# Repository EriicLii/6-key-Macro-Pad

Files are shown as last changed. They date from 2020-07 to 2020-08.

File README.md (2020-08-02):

# 6 Key Macro Pad

Footprints from https://github.com/tmk/keyboard_parts.pretty and https://github.com/egladman/keebs.pretty

Components used from https://github.com/tmk/kicad_lib_tmk

Built with SMD components, and ATMega32u4.

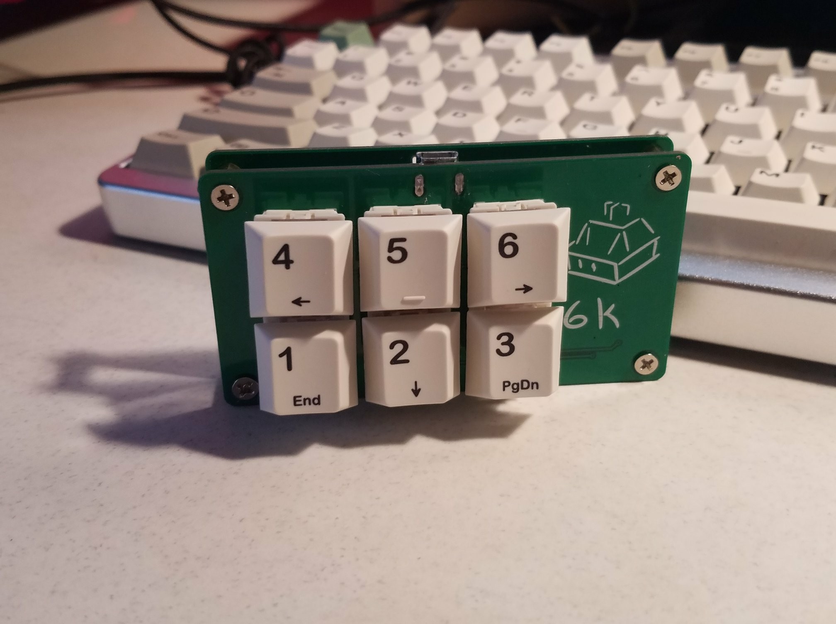
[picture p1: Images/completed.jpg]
build image


PCB:
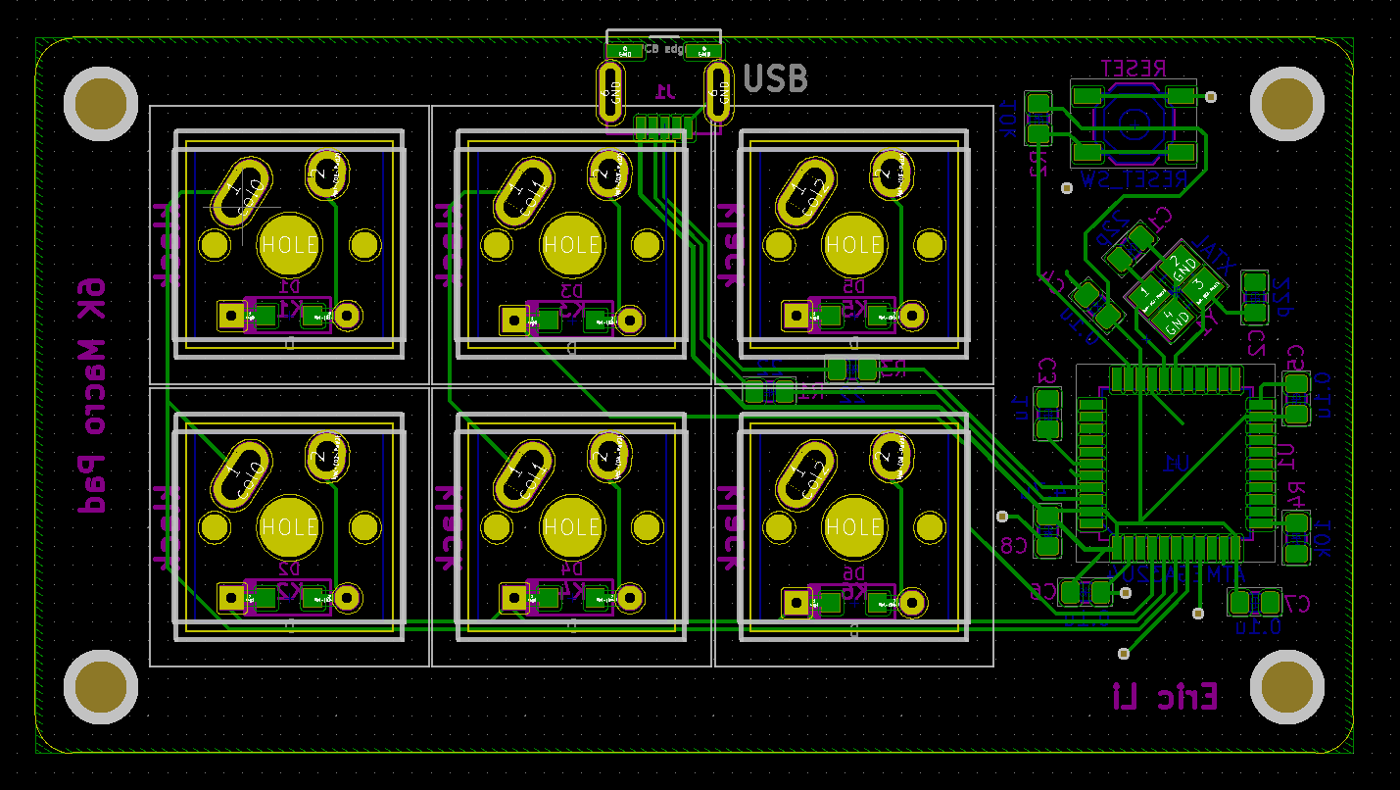
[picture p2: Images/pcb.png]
PCB Image


Schematic:
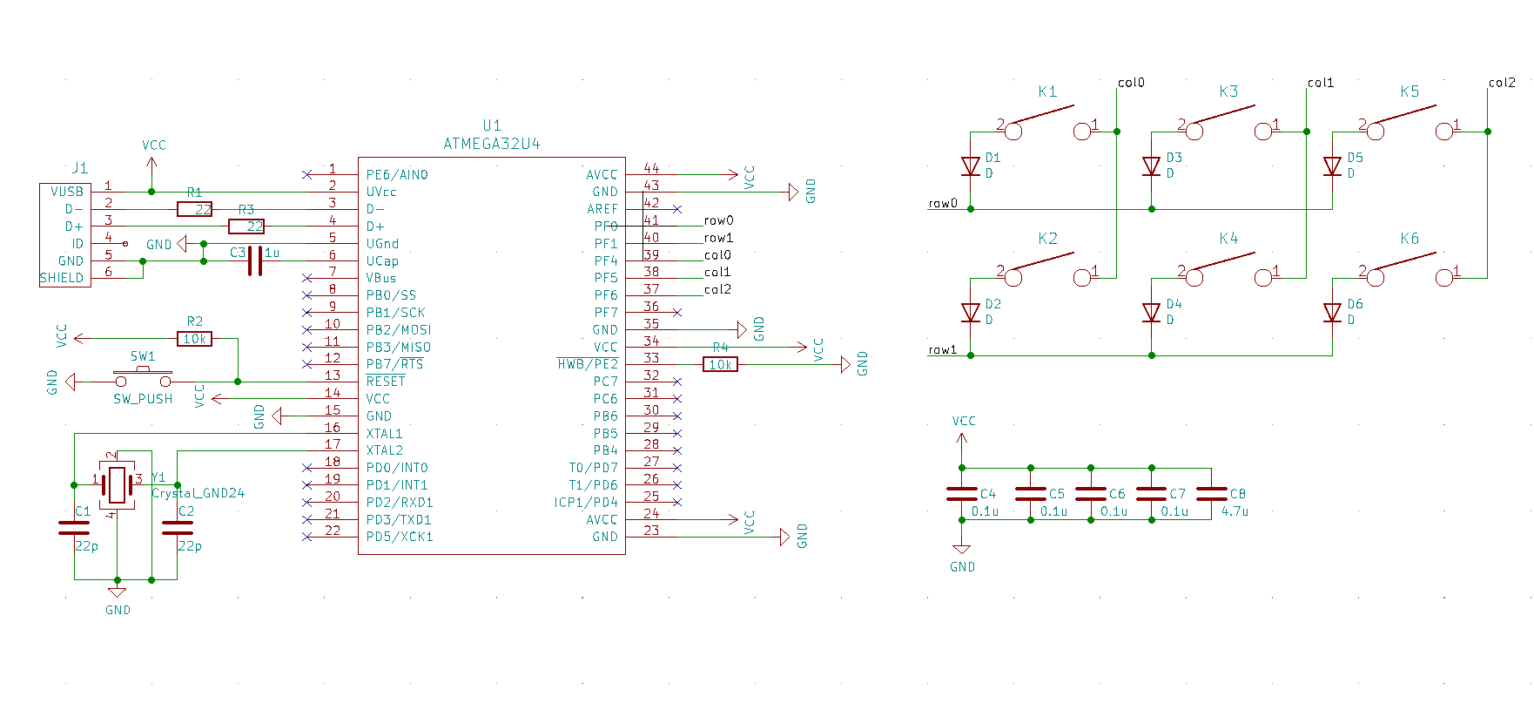
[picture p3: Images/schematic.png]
Schematic


## Update 7/31
Finally got to soldering the parts. 
Had an issue with discovering the DFU. At first I though the microcontroller didn't come with the HWBE bit set from factory. However after painstakingly soldering the MOSI, MISO and SCK pins, then setting the fuses through ISP -- still no dice. I finally noticed that I hadn't wired VBus to VCC in my schematic. I guess I got taught the lesson of measuring thrice before sending it to fabrication.

QMK firmware setup was very easy. Kudos to everyone involved in the project as the abundance documentation and organization made it simple to get a new keyboard firmware set up. Right now I only have the option to manually change the keymaps in QMK then recompile. I'll perhaps attempt to make a Via keymap later as well. (Also I need to add pictures of the build!)

## Update 8/2
Added some pictures. You can see how I had to wire VCC to the Vbus pin on the back of the board.

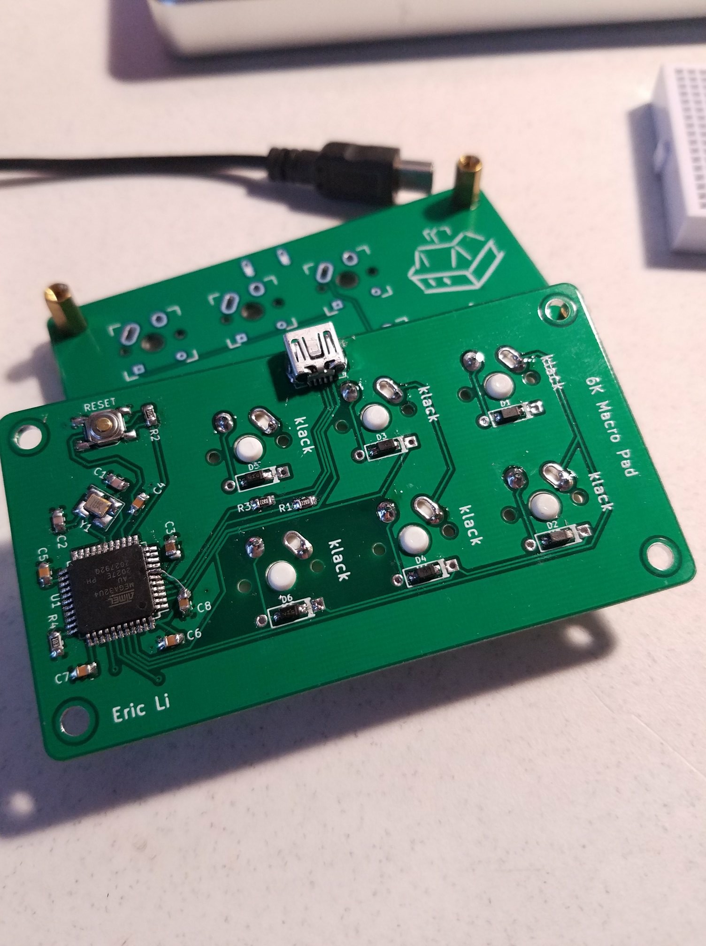
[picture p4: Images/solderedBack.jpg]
back image


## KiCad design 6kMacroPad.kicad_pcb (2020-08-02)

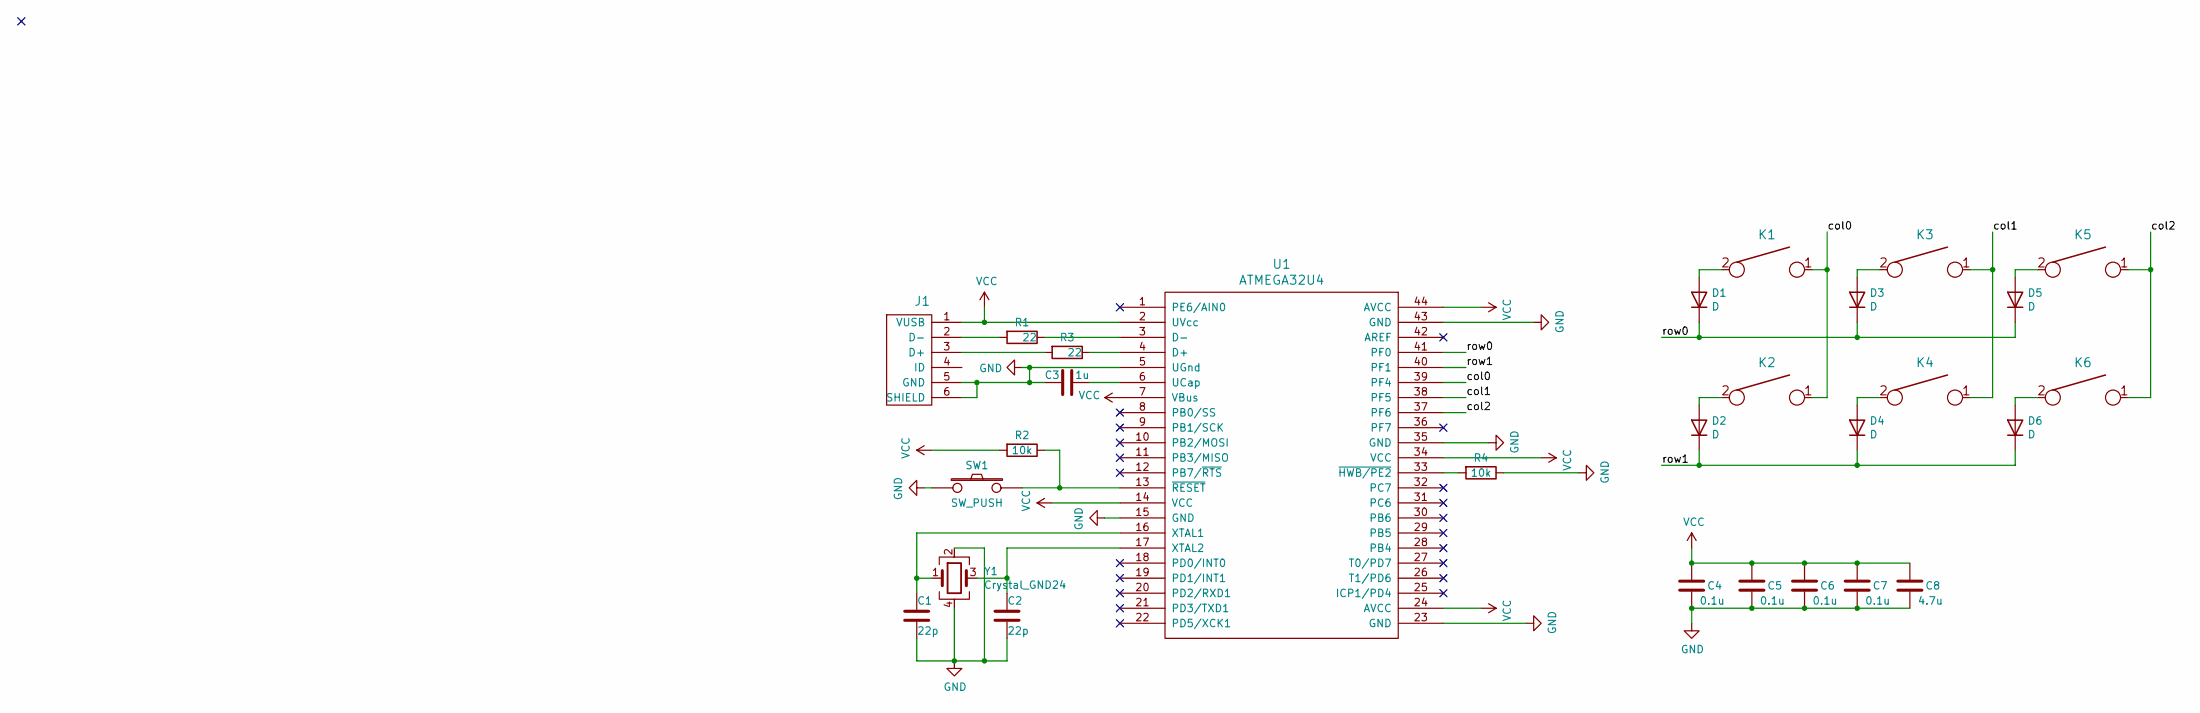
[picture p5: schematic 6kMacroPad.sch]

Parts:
C1, C2: 22p; C_0805_2012Metric_Pad1.15x1.40mm_HandSolder
C3: 1u; C_0805_2012Metric_Pad1.15x1.40mm_HandSolder
C4, C5, C6, C7: 0.1u; C_0805_2012Metric_Pad1.15x1.40mm_HandSolder
C8: 4.7u; C_0805_2012Metric_Pad1.15x1.40mm_HandSolder
D1, D2, D3, D4, D5, D6: D; D_SOD123_axial
J1: USB_mini_micro_B; USB_miniB_hirose_5S8
K1, K2, K3, K4, K5, K6: KEYSW; Mx_Alps_100
R1, R3: 22; R_0805_2012Metric_Pad1.15x1.40mm_HandSolder
R2, R4: 10k; R_0805_2012Metric_Pad1.15x1.40mm_HandSolder
SW1: SW_PUSH; SW_SPST_TL3342
U1: ATMEGA32U4; TQFP-44_10x10mm_P0.8mm
Y1: Crystal_GND24; Crystal_SMD_SeikoEpson_FA238-4Pin_3.2x2.5mm_HandSoldering

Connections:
/col0: K1.1, K2.1, U1.39 (PF4)
/col1: K3.1, K4.1, U1.38 (PF5)
/col2: K5.1, K6.1, U1.37 (PF6)
/row0: D1.1 (K), D3.1 (K), D5.1 (K), U1.41 (PF0)
/row1: D2.1 (K), D4.1 (K), D6.1 (K), U1.40 (PF1)
GND: C1.2, C2.2, C3.2, C4.2, C5.2, C6.2, C7.2, C8.2, J1.5 (GND), J1.6 (SHIELD), R4.1, SW1.1, U1.5 (UGnd), U1.15 (GND), U1.23 (GND), U1.35 (GND), U1.43 (GND), Y1.2, Y1.4
unnamed: C1.1, U1.16 (XTAL1), Y1.1
unnamed: C2.1, U1.17 (XTAL2), Y1.3
unnamed: C3.1, U1.6 (UCap)
unnamed: D1.2 (A), K1.2
unnamed: D2.2 (A), K2.2
unnamed: D3.2 (A), K3.2
unnamed: D4.2 (A), K4.2
unnamed: D5.2 (A), K5.2
unnamed: D6.2 (A), K6.2
unnamed: J1.2 (D-), R1.2
unnamed: J1.3 (D+), R3.2
unnamed: R1.1, U1.3 (D-)
unnamed: R2.1, SW1.2, U1.13 (~RESET)
unnamed: R3.1, U1.4 (D+)
unnamed: R4.2, U1.33 (~HWB/PE2)
VCC: C4.1, C5.1, C6.1, C7.1, C8.1, J1.1 (VUSB), R2.2, U1.2 (UVcc), U1.7 (VBus), U1.14 (VCC), U1.24 (AVCC), U1.34 (VCC), U1.44 (AVCC)

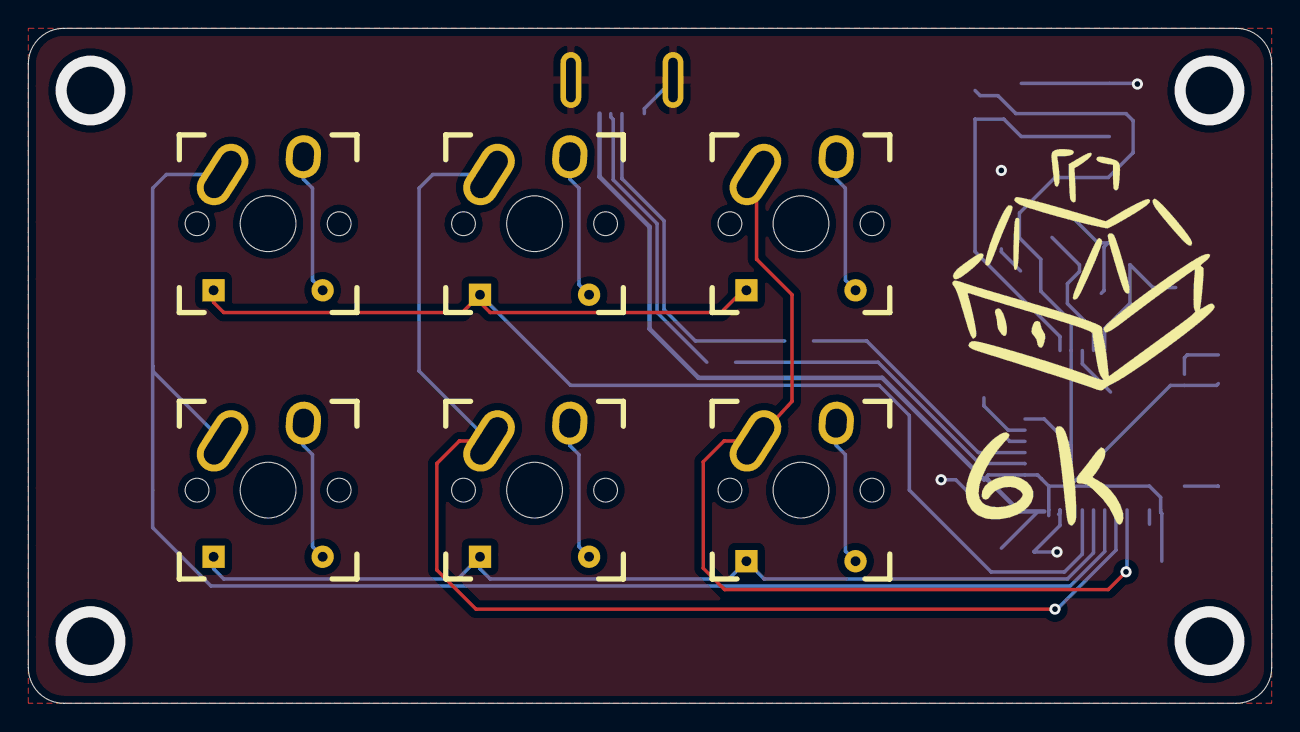
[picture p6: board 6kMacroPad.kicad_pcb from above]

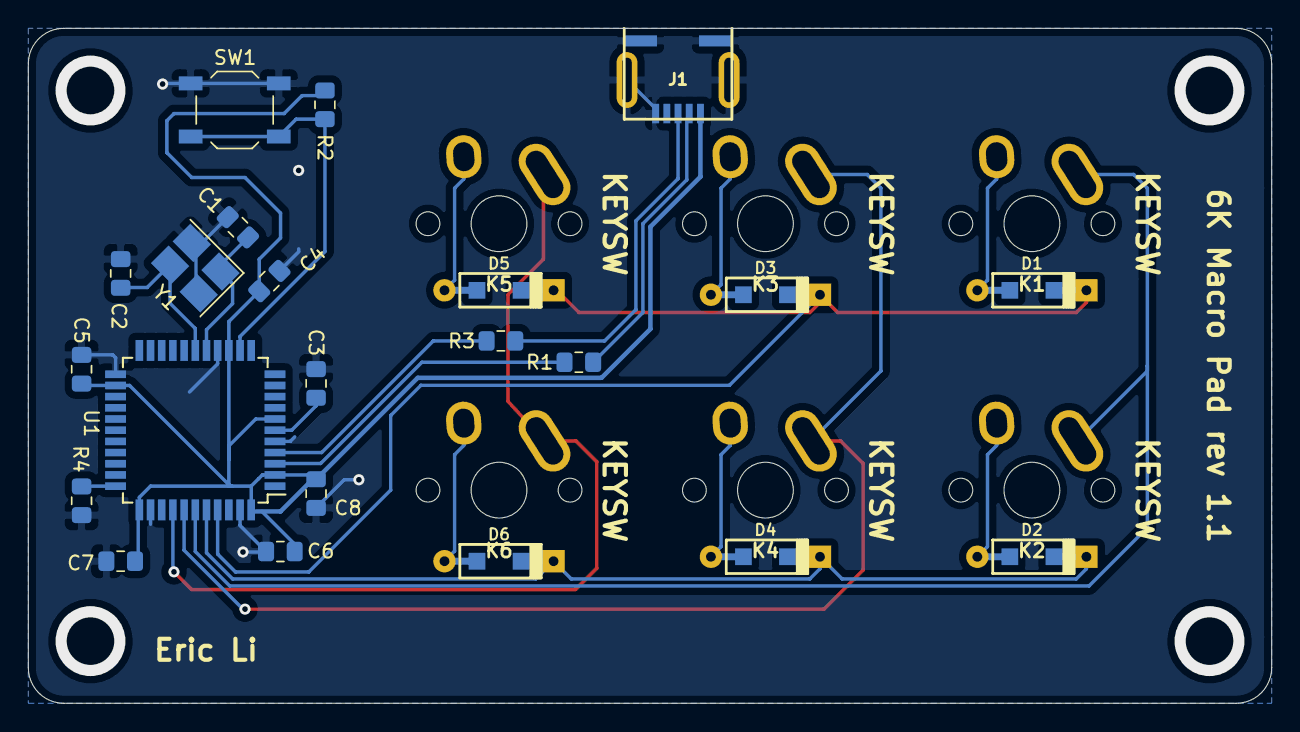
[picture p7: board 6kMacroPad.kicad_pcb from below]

Board: 2 copper layers, 88.9 x 48.3 mm, 28 parts (22 on the bottom side), 22 nets.

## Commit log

2020-08-02 Fixed Vbus not connected, added pics
    - now Vbus is connected to VCC
    - added more pics of the build
    [6kMacroPad.kicad_pcb, 6kMacroPad.sch]
2020-08-02 Fixed PCB and Schematic links in README
